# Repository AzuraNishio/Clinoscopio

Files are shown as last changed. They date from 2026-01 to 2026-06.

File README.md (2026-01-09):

<details>
<summary><strong>Clinoscopio – Project Overview</strong></summary>

# Clinoscopio

A low-cost, 3D-printed clinoscope for plant growth and gravitropism experiments.

Clinoscopio is designed to be simple to build, easy to reproduce, and accessible, while still providing a motion profile suitable for gravity-averaging experiments.

---

## Materials

- 3D printed parts (all structural components)
- 1 stepper motor
- Stepper motor driver of choice

No additional mechanical components are required.

---

## Control and Electronics

- Control code is provided for:
  - Arduino
  - ESP32
- Multiple clinoscopes can be daisy-chained
- A single controller can operate multiple units simultaneously

---

## Motion and Mechanical Design

- Single-motor design
- Motion transmitted through a moving two-gear system
- Snap-fit assembly (no screws required)

The rotation pattern is calculated such that, over one full cycle:
- The integral of gravity along all axes is equal to zero
- The variance of gravity is equal on all axes

One full cycle consists of five rotations of the main axle.

---

## Assembly

- Fully snap-fit construction
- No assembly video is available yet (planned for a future update)

---

## Status

This project is under active development.  
This README is temporary and will be expanded with additional documentation and media.

</details>

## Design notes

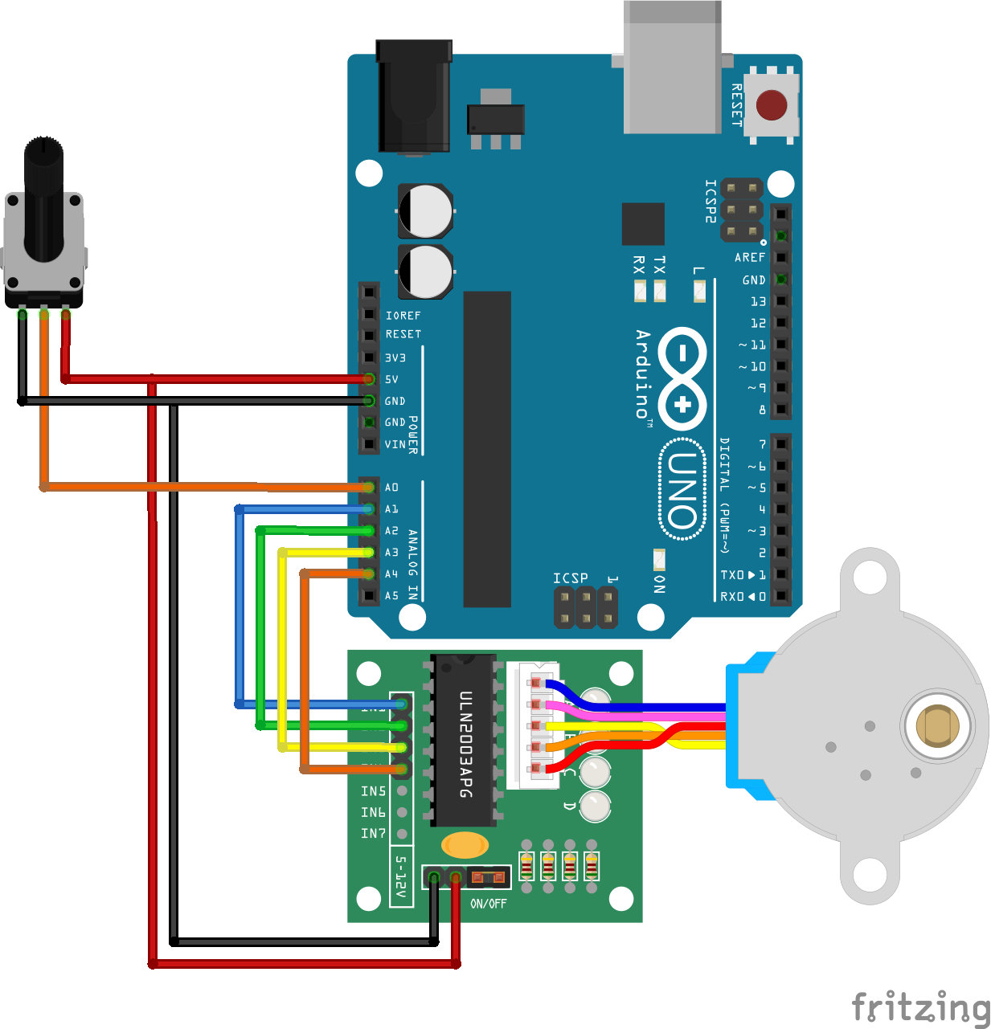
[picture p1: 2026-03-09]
circuito/Controle de velocidade analógico arduino.png

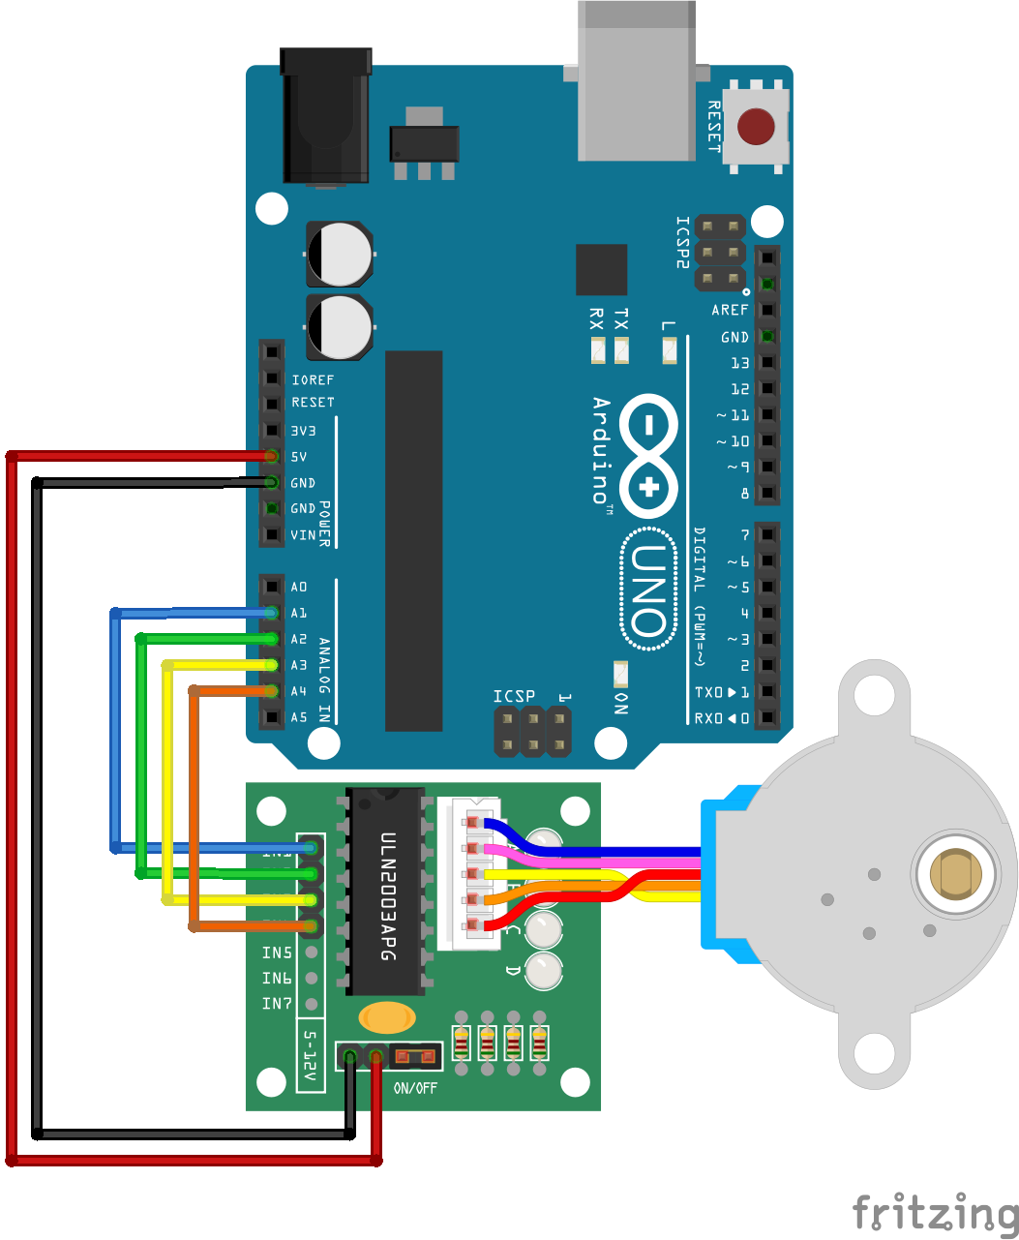
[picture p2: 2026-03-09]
circuito/Ligação simples arduino - driver - stepper.png

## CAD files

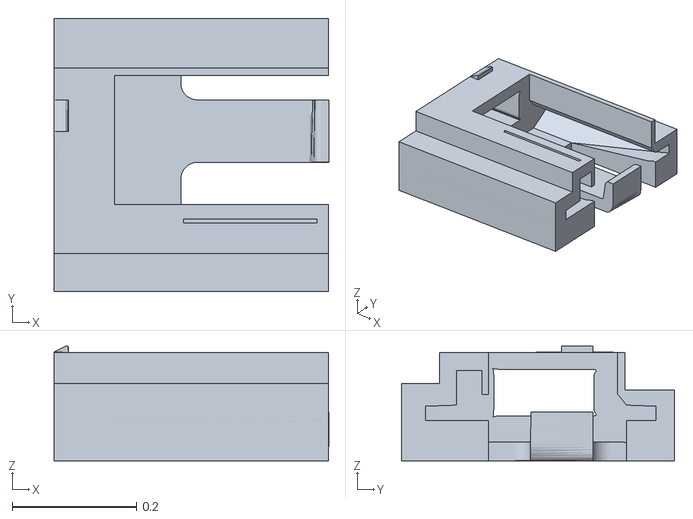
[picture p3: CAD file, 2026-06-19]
modelo/Clinostato v2.8-Suporte driver motor de passo.stl
0.443 x 0.44 x 0.185

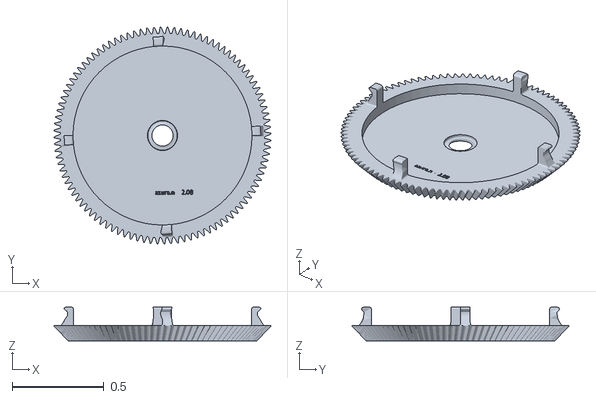
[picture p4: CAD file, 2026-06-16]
modelo/Clinostato v2.8-Engrenagem grande.stl
1.18 x 1.18 x 0.184

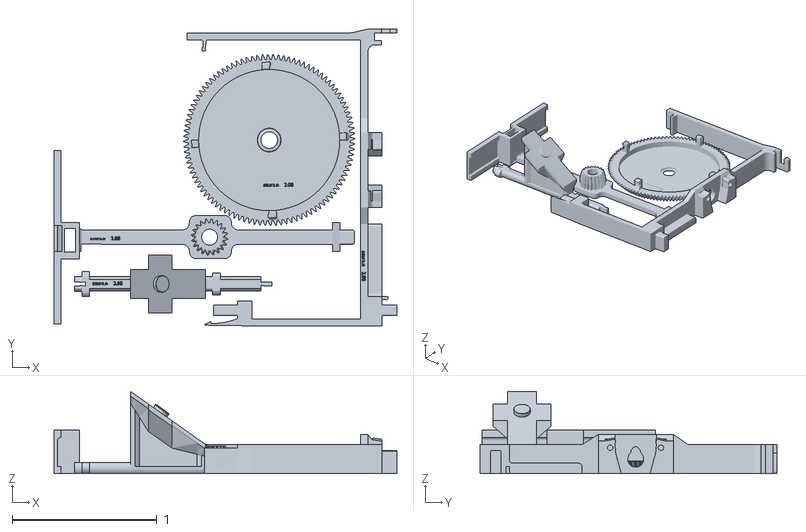
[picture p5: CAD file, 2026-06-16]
modelo/Clinostato v2.8-modelo completo.stl
2.37 x 2.05 x 0.567

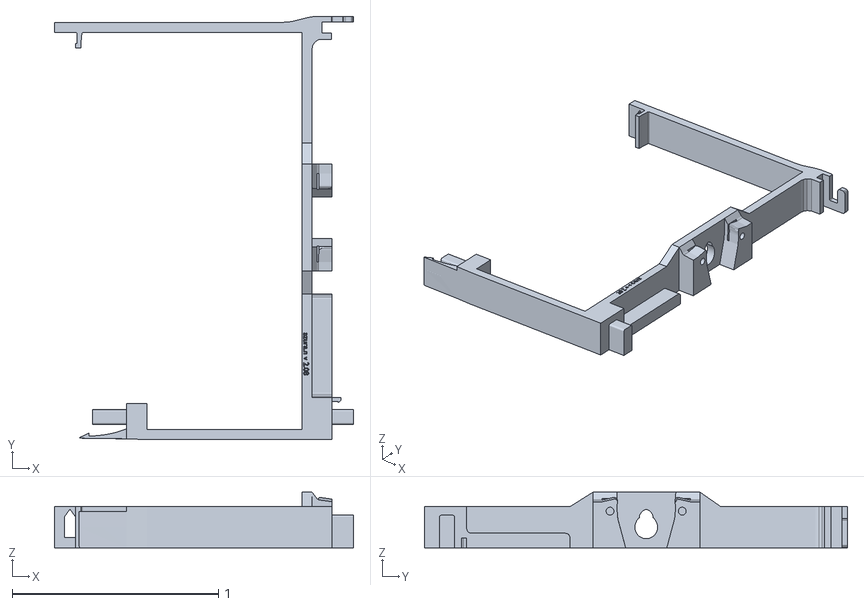
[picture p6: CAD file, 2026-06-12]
modelo/Clinostato v2.8-Base lado motor.stl
1.45 x 2.05 x 0.27

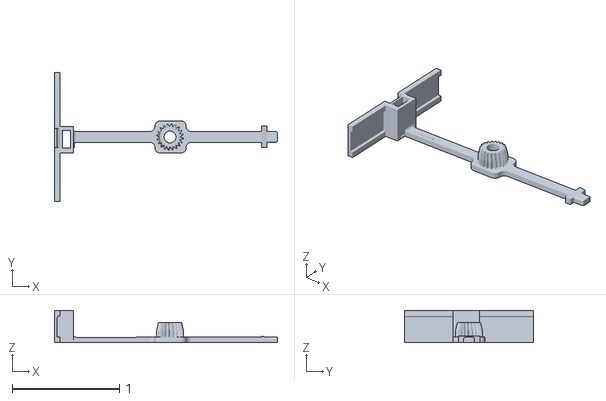
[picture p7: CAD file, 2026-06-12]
modelo/Clinostato v2.8-Base lado engrenagem.stl
2.08 x 1.20 x 0.3

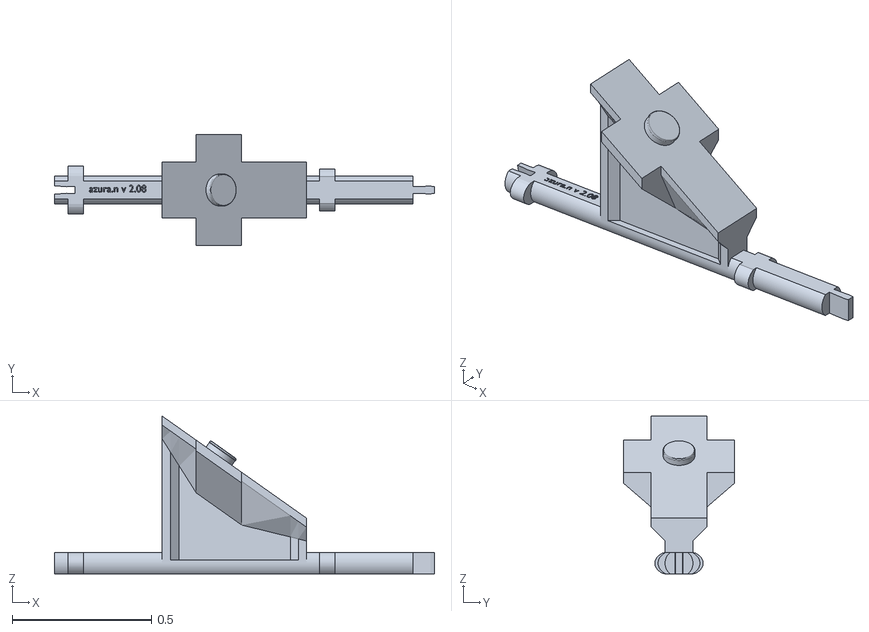
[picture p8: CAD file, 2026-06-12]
modelo/Clinostato v2.8-Eixo.stl
1.36 x 0.4 x 0.567

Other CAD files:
modelo/Clinostato v2.8.blend

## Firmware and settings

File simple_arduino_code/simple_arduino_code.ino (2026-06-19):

// Configurações clinoscópio
const int passosPorBloco = 16; //Quantos passos por bloco, usar multiplos de 4!
const int passosPorRotacao = 1024; //Quantos passos por rotação completa 

float RPM = 3; //Velocidade em rotações por minuto

const float millisPorPasso = 15; //milissegundos por passo 

const int portasMotorDePasso[4][4] = {
  {4, 5, 6, 7},
  {8, 9, 10, 11},
  {22, 24, 26, 28},
  {30, 32, 34, 36}
}; //Portas dos motores de passo

// Código
const int padraoMotor[4][4] = {
  {1, 0, 0, 0},
  {0, 1, 0, 0},
  {0, 0, 1, 0},
  {0, 0, 0, 1}
};

const int padraoMotorForte[4][4] = {
  {1, 1, 0, 0},
  {0, 1, 1, 0},
  {0, 0, 1, 1},
  {1, 0, 0, 1}
};



void setup() {
  for (int i = 0; i<4; i++){
    pinMode(portasMotorDePasso[i], OUTPUT);
  }
  pinMode(A0, INPUT);
  pinMode(A1, INPUT);
  pinMode(A2, INPUT);
  pinMode(A3, INPUT);
  pinMode(A4, INPUT);
  pinMode(A5, INPUT);
  pinMode(A6, INPUT);
  pinMode(A7, INPUT);

  Serial.begin(9600);
}

void updMotor(float step){
  int state = int(step) % 4;
  if (state < 0) state += 4;
  
  for (int i = 0; i<4; i++){
    for (int j = 0; j<4; j++){
      digitalWrite(portasMotorDePasso[j][i], padraoMotor[state][i]);
    }
  }
}

void updMotorForte(float step){
  int state = int(step) % 4;
  if (state < 0) state += 4;
  
  for (int i = 0; i<4; i++){
    for (int j = 0; j<4; j++){
      digitalWrite(portasMotorDePasso[j][i], padraoMotorForte[state][i]);
    }
  }
}

void pararMotor(){
  for (int i = 0; i<4; i++){
    for (int j = 0; j<4; j++){
      digitalWrite(portasMotorDePasso[j][i], 0);
    }
  }
}

int configVelocidade(){
  int max = 0;
  int speed = 0;
  int count = 0;
  for (int p = 0; p<9; p++){
    int v = analogRead(A0 + p);
    if (v > max){
      max = v;
      speed = p;
    }
  }
  if(max < 1000){
    speed = 0;
  }
  return speed;
}

void loop(){
  RPM = configVelocidade() * 0.5;
  float MillisPorBloco = passosPorBloco / ((RPM / 60000) * passosPorRotacao);
  unsigned long time = millis();
  unsigned long blocoMs = (unsigned long)MillisPorBloco;
  unsigned long cicle = time % blocoMs;

  


  
  if (cicle < (unsigned long)(passosPorBloco * millisPorPasso)){
    updMotor(cicle / (unsigned long)millisPorPasso);
  } else {
    pararMotor();
  }
}

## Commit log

2026-01-09 Added washers and petri dish holder
    [STL V2 1.0.stl, STL V2 1.1.stl, modelo v2.blend]
2026-01-14 increased clamps size
    [STL V2 1.2.stl, modelo v2-Vivenciando iteracao 2.002.3mf, modelo v2.blend]
2026-02-27 código arduino simples
    [modelo v2.blend]
2026-03-09 Ajustes nos encaixes snap
    [modelo v2.blend]
2026-03-09 Better clamps
    [modelo v2.blend]
2026-03-09 files cleanup
    [STL V2 1.0.stl, STL V2 1.1.stl, STL V2 1.2.stl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]
2026-03-09 diagramas elétricos
    [Controle de velocidade analógico arduino.fzz, Ligação simples arduino - driver - stepper.fzz, modelo v2.blend]
2026-05-23 New sample attachment with rubber bands
    [modelo v2-Engrenagem grande.stl, modelo v2.blend]
2026-05-29 garraws altas
    [modelo v2 1.6.stl, modelo v2-Engrenagem grande alta.stl, modelo v2.blend]
2026-06-09 Reorganized and openned 5 mm for petri dish
    [Modelo V2 1.5.stl, modelo v2 1.4.stl, modelo v2 1.6.stl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]
2026-06-12 File reorganization
    Adding version name to files
    [Clinostato v2.8.blend, modelo v2-Base lado engrenagem.stl, modelo v2-Base lado motor.stl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]
2026-06-12 2.8
    melhor encaixe ente anexos, aumentado algumas margens, adicionado marca com versão
    [Clinostato v2.8-Base lado engrenagem.stl, Clinostato v2.8-Base lado motor.stl, Clinostato v2.8-Eixo.stl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]
2026-06-16 V2.8b
    gancho elástico mais curvado
    [Clinostato v2.8-Engrenagem grande.stl, Clinostato v2.8-modelo completo.stl, Clinostato v2.8.blend]
2026-06-19 Added driver support base
    [Clinostato v2.8-Suporte driver motor de passo.stl, Clinostato v2.8.blend]
